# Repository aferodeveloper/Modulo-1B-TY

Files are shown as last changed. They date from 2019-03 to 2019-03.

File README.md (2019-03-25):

# INTRODUCTION
Modulo-1B-TY is a development board for the Afero ASR-1B Secure BLE radio architecture (based on the nRF52832 BLE chipset).  The Modulo-1B-TY uses the pre-certified Taiyo Yuden EYSHCNZWZ module + the Afero Hardware Security Module.

Additional Features:
 * Board supports power from USB as well as a Vin over a relatively wide voltage range
 * New and improved switch (first used on Modulo2a)
 * Use of the Taiyo Yuden EYSHCNZWZ module gives the board FCC/IC and Telec certification

For more information, please see the Afero developers site: https://developer.afero.io

# Design Information
The Modulo-1B-TY design was built using Altium.  The entire Altium project, including scripts that generate the output files, is included.

## Manifest (abridged)
 * **Modulo-1B-TY.PrjPcb** is the toplevel Altium project file.
 * **Modulo-1B-TY.SchDoc** is the Altium schematic file.
 * **Modulo-1B-TY.PcbDoc** is the Altium layout file.
 * **AssyDrawing.PCBDwf** and **FabDrawing.PCBDwf** are drawing templates for the Assembly and Fabrication drawings.
 * **outputs.OutJob** is the "script" for Altium that you can use to generate all of the needed output files (pdf files, gerbers, pick and place info, et cetera).
 * **Modulo-1B-TY.pdf** pdf of the schematics; autogenerated.
 * **Modulo-1B-TY-fabrication.pdf** pdf of the board fabrication drawing; autogenerated.
 * **Modulo-1B-TY-Assy.pdf** pdf of the assembly drawing; autogenerated.
 * **gerbers** is the directory where the Gerber output files and ODB++ files are located.  These are the files that one would use when you release the board to fab and assembly; autogenerated.
 * **gerbers/Modulo-1B-TY_BOM.xls** is the Bill of Materials for the board; autogenerated.
 * **LICENSE.txt** Apache 2.0 license governing the use of this design.
 * **NOTICE** Copyright information.
 * **README.md** This file.

Please note that the Afero Secure Radio stack firmware and hardware security modules included in the design are not publicly available.  Please contact Afero about licensing these items.

# CONTRIBUTORS
Original design by Afero, Inc.

Copyright 2018, 2019 Afero, Inc.

Licensed under the Apache 2.0 license; check LICENSE.txt for more information.  All text above must be included in any redistribution.

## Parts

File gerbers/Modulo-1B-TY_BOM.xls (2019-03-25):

item_number | Comment | Description | Quantity | Designator | Footprint | LibRef | Manufacturer | Manufacturer Part Number
E-CAP-00106-00 | 12pF | Capacitor, C0G | 3.0 | C1, C13, C14 | 0402C-GENERIC | 0402C-12p | Murata | GJM1555C1H120FB01D
E-CAP-00066-00 | 4.7uF | Capacitor | 4.0 | C2, C4, C8, C15 | 0603C-GENERIC | 0603C-4u7 | Murata | GRM188R61C475KAAJD
E-CAP-00004-00 | .1uF | Capacitor, MLCC | 4.0 | C3, C6, C9, C10 | 0402C-GENERIC | 0402C-100n | Murata | GRM155R61H104KE19D
E-CAP-00020-00 | 1uF | Capacitor, MLCC | 2.0 | C5, C7 | 0402C-GENERIC | 0402C-1u | Murata Electronics | GRM155R60J105ME19J
E-CAP-00019-00 | 47pF | Capacitor, C0G | 2.0 | C11, C12 | 0402C-GENERIC | 0402C-47p | Murata | GRM1555C1H470JZ01D
E-DIO-00010-00 | BAT54CL | Dual Common Cathode Schottky Diodes | 1.0 | D1 | SOT23 | BAT54CL | ON Semiconductor | BAT54CLT1G
E-LED-00009-00 | Orange | LED_0603 | 1.0 | D2 | 0603LED | LED_0603 | Vishay Lite-On | LTST-C190KAKT
E-DIO-00008-00 | TPD1E05U06 | TVS Diode | 5.0 | D3, D4, D5, D6, D7 | SON70P100X45-2N | TPD1E05U06 | Texas Instruments | TPD1E05U06DPYR
M-CON-00058-00 | HDR-1x18 |  | 2.0 | J1, J2 | HDR-1X18 | HDR-1x18
E-ICS-00091-00 | EYSHCNZWZ | Bluetooth 5.0 Low Energy Module | 1.0 | MOD1 | EYSHCNZWZ | EYSHCNZWZ | Taiyo Yuden | EYSHCNZWZ
 | 2N7002 | MOSFET N-CH 60V 115mA SOT23 | 1.0 | Q1 | SOT23 | Nch_MOSFET_2N7002 | On Semiconductor | 2N7002
E-RES-00039-00 | 4.7k | Resistor 4k7 | 2.0 | R1, R2 | 0402R-GENERIC | 0402R-4k7 | Panasonic | ERJ-2GEJ472X
E-RES-00008-00 | 100 | Resistor 100R | 2.0 | R3, R13 | 0402R-GENERIC | 0402R-100R | Vishay Dale | CRCW0402100RFKED
E-RES-00001-00 | 10k | Resistor 10k | 1.0 | R5 | 0402R-GENERIC | 0402R-10k | Vishay Dale | CRCW040210K0JNED
E-RES-00019-00 | 0 | Resistor 0R | 1.0 | R7 | 0603R-generic | 0603R-0R0 | Panasonic | ERJ-3GEY0R00V
E-RES-00012-00 | 100k | Resistor 100k | 1.0 | R8 | 0402R-GENERIC | 0402R-100k | Panasonic | ERJ-2GEJ104X
E-RES-00002-00 | 1k | Resistor 1k | 3.0 | R9, R10, R11 | 0402R-GENERIC | 0402R-1k | Yageo | RT0402-FRE071KL
E-RES-00007-00 | 27 | Resistor 27R | 2.0 | R12, R14 | 0402R-GENERIC | 0402R-27R | Vishay | CRCW040227R0FKED
item_name | 0 | Resistor 0R | 1.0 | R15 | 0402R-GENERIC | 0402R-0R0 | Yageo | RC0402FR-070RL
E-SWI-00020-00 | FSMSM | SMD Tact Switch | 1.0 | S1 | FSMSM | FSMSM | TE Connectivity Alcoswitch | FSMSM
E-ICS-00072-00 | ATECC508A | Afero Custom CryptoAuthentication Device | 1.0 | U1 | SON50P300X60-8N | ATECC508A | Microchip / Atmel | ATECC508A-MAHCZ-T
E-ICS-00092-00 | S-1313A33-M5T1U3 | Low Current Consumption LDO | 1.0 | U2 | SOT95P275X130-5N | S-1313A33-M5T1U3 | Seiko | S-1313A33-M5T1U3
E-ICS-00053-00 | FT230XQ | USB to UART Bridge | 1.0 | U3 | VQFN65P400X400X90-16N | FT230XQ | FTDI | FT230XQ-R
M-CON-00011-00 | 10103594-0001LF | MICRO USB B | 1.0 | USB1 | 10103594-0001LF | 10103594-0001LF | Amphenol FCI | 10103594-0001LF

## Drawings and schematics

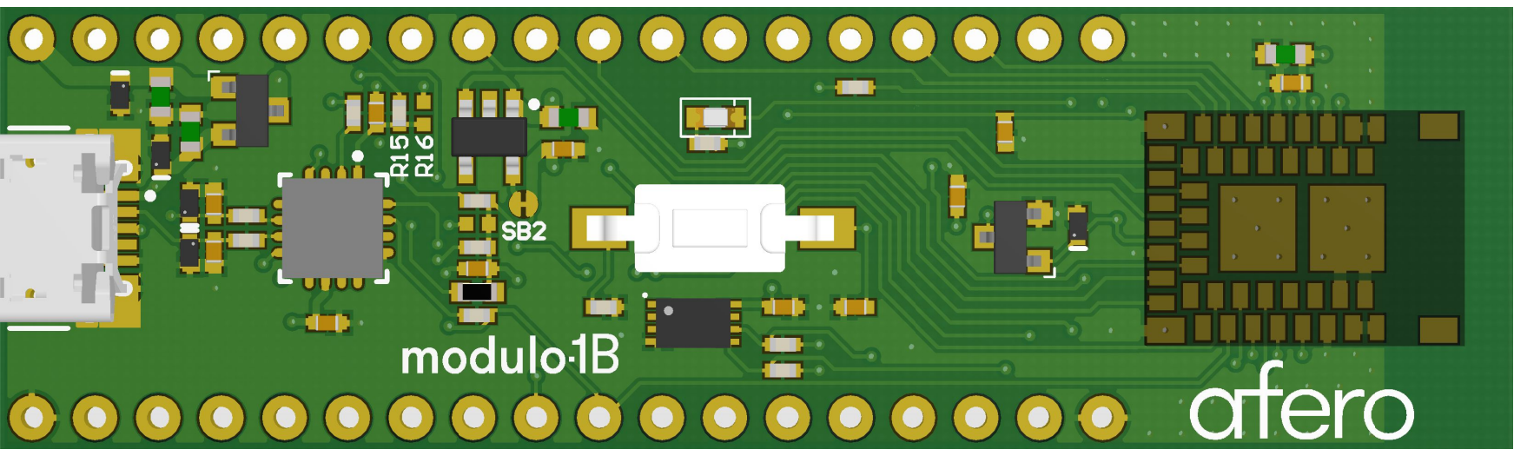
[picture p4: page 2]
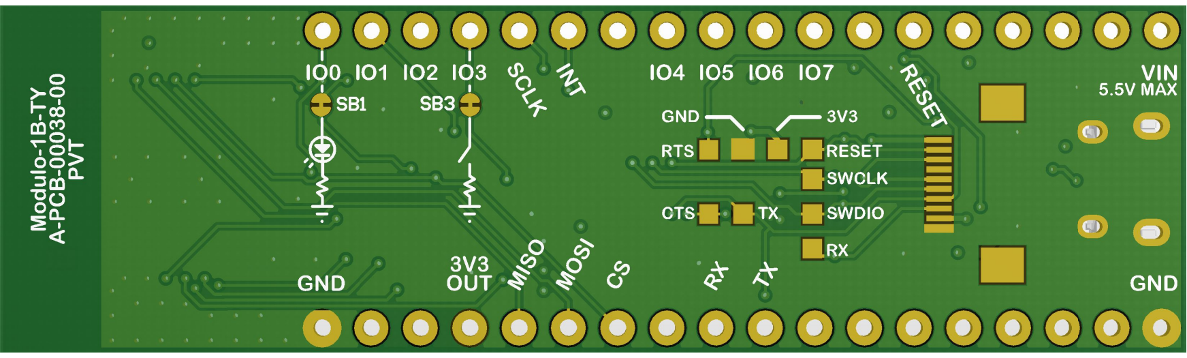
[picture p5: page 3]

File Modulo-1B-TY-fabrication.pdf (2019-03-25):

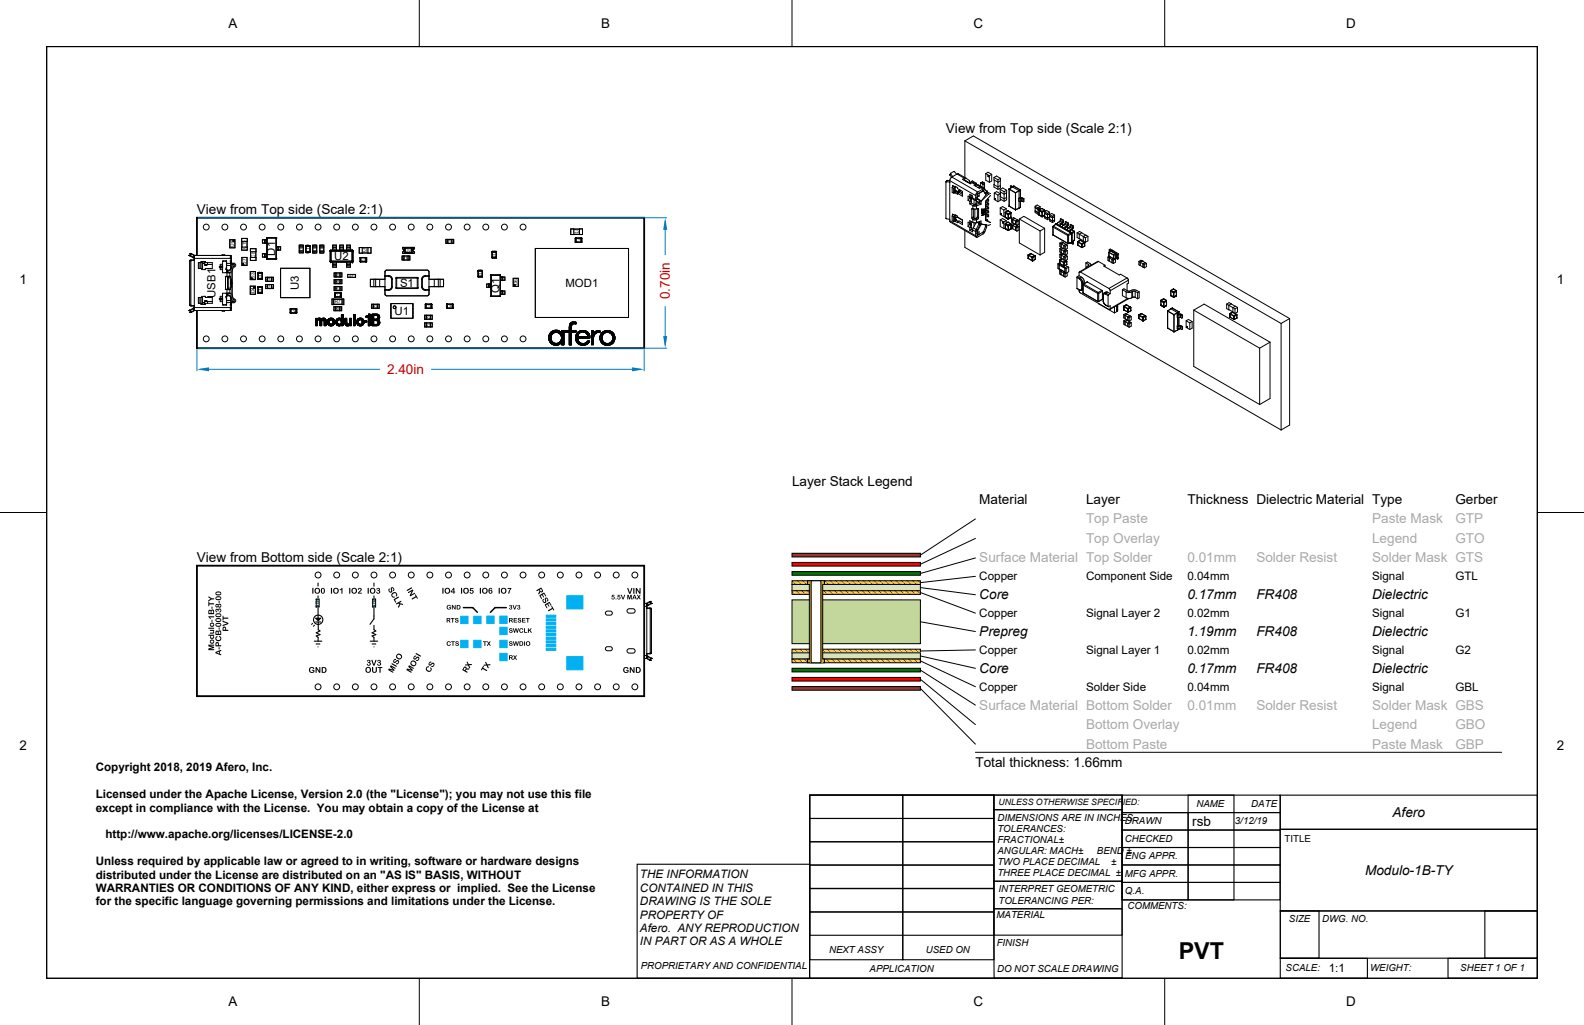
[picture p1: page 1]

View from Top side (Scale 2:1)

View from Bottom side (Scale 2:1)

Licensed under the Apache License, Version 2.0 (the "License"); you may not use this file
except in compliance with the License. You may obtain a copy of the License at

UNLESS OTHERWISE SPECIFIED:
DIMENSIONS ARE IN INCHES
TOLERANCES:
FRACTIONAL±
TWO PLACE DECIMAL ±
THREE PLACE DECIMAL ±
INTERPRET GEOMETRIC
TOLERANCING PER:
MATERIAL

http://www.apache.org/licenses/LICENSE-2.0

Unless required by applicable law or agreed to in writing, software or hardware designs
distributed under the License are distributed on an "AS IS" BASIS, WITHOUT
WARRANTIES OR CONDITIONS OF ANY KIND, either express or implied. See the License
for the specific language governing permissions and limitations under the License.

THE INFORMATION
CONTAINED IN THIS
DRAWING IS THE SOLE
PROPERTY OF
Afero. ANY REPRODUCTION
IN PART OR AS A WHOLE

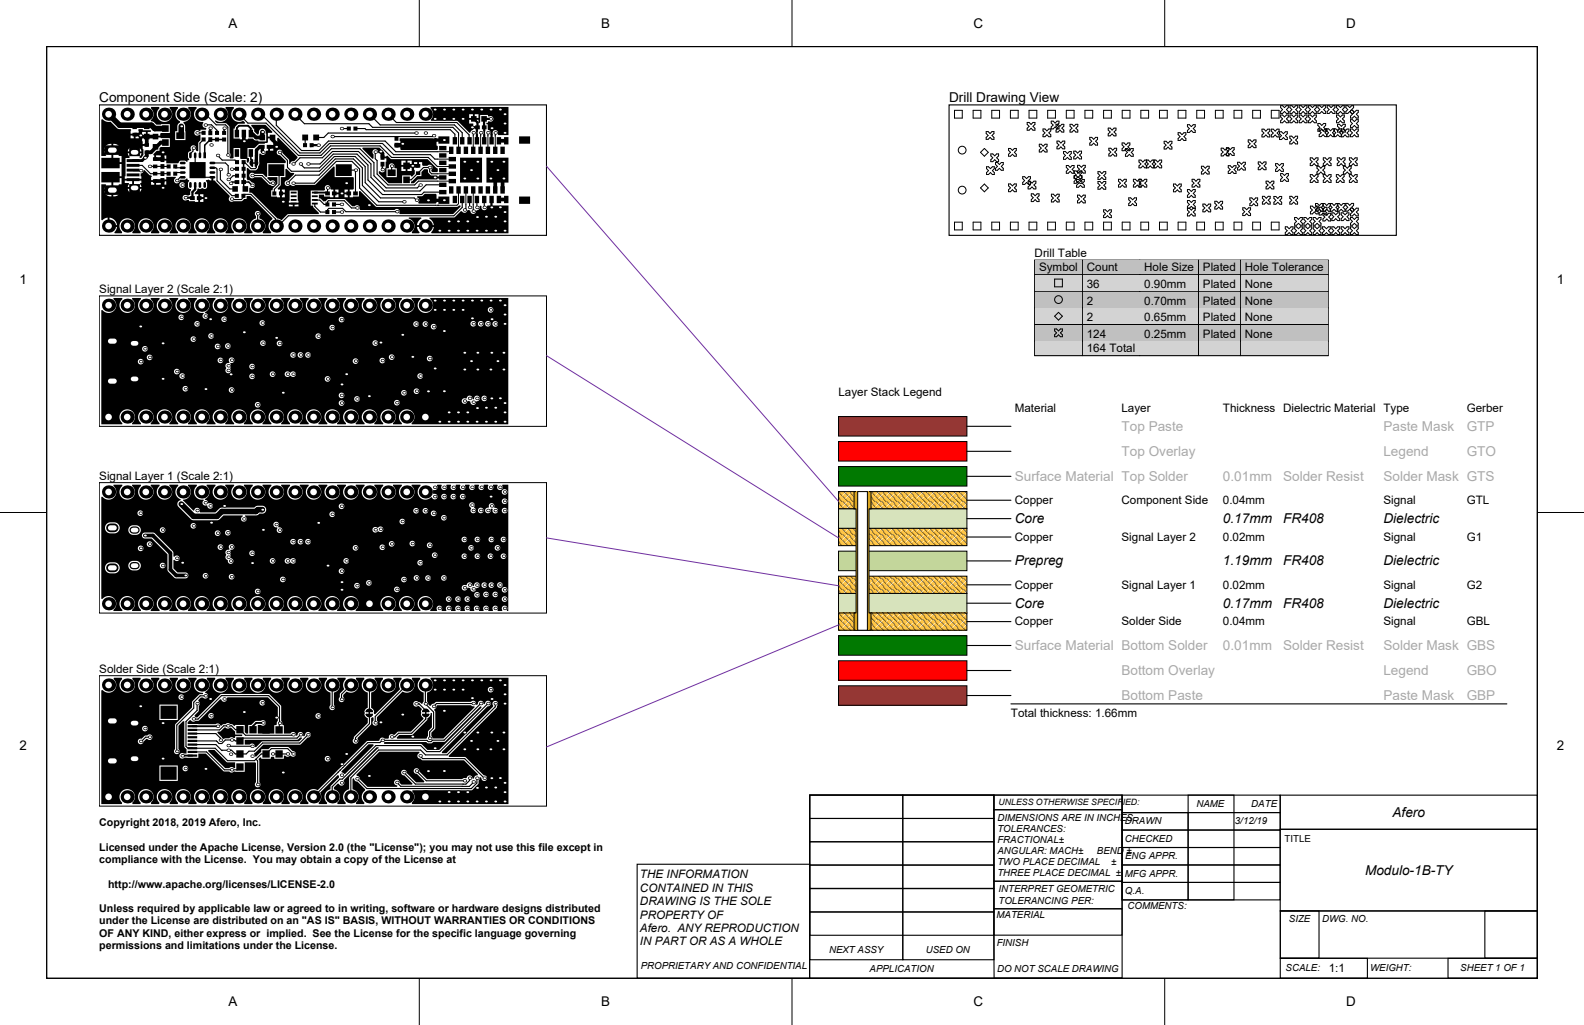
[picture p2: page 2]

Symbol | Count | Hole Size | Plated | Hole Tolerance

36 | 0.90mm | Plated | None
2 | 0.70mm | Plated | None
2 | 0.65mm | Plated | None
124 | 0.25mm | Plated | None
164 Total

UNLESS OTHERWISE SPECIFIED: | | NAME | DATE | Afero
DIMENSIONS ARE IN INCHES TOLERANCES: FRACTIONAL± ANGULAR: MACH± BEND ± TWO PLACE DECIMAL ± THREE PLACE DECIMAL ± | DRAWN | | 3/12/19

CHECKED | | | TITLE Modulo-1B-TY
ENG APPR.

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

THE INFORMATION CONTAINED IN THIS DRAWING IS THE SOLE PROPERTY OF Afero. ANY REPRODUCTION IN PART OR AS A WHOLE PROPRIETARY AND CONFIDENTIAL | | | MFG APPR.

http://www.apache.org/licenses/LICENSE-2.0

INTERPRET GEOMETRIC TOLERANCING PER: | Q.A.

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

MATERIAL | | SIZE | DWG. NO.

NEXT ASSY | USED ON | FINISH DO NOT SCALE DRAWING

APPLICATION | | | 1:1

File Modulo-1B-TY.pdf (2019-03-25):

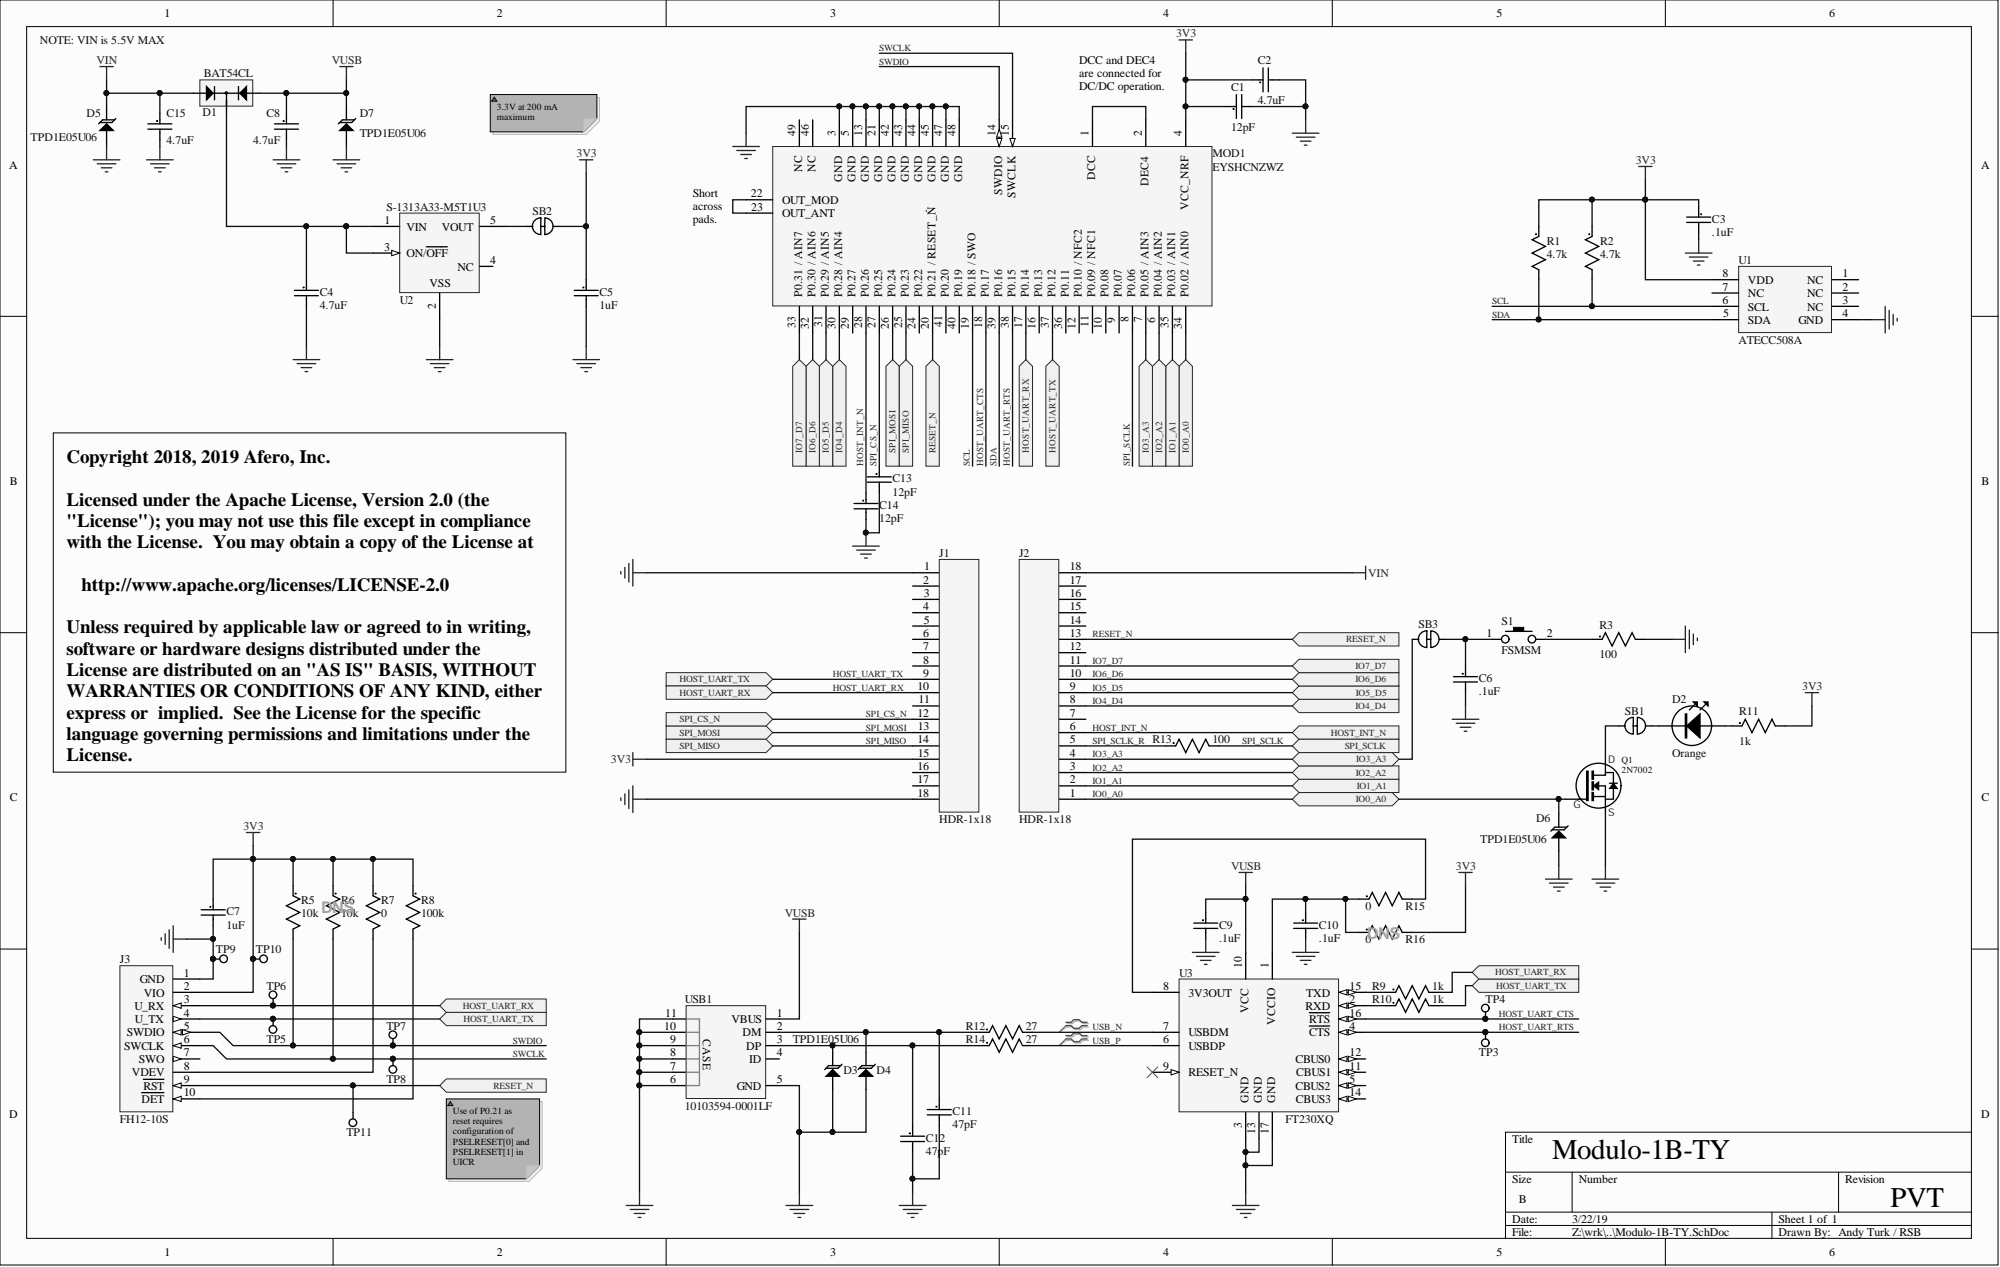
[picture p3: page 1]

NOTE: VIN is 5.5V MAX

Licensed under the Apache License, Version 2.0 (the
"License"); you may not use this file except in compliance
with the License. You may obtain a copy of the License at

http://www.apache.org/licenses/LICENSE-2.0

Unless required by applicable law or agreed to in writing,
software or hardware designs distributed under the
License are distributed on an "AS IS" BASIS, WITHOUT
WARRANTIES OR CONDITIONS OF ANY KIND, either
express or implied. See the License for the specific
language governing permissions and limitations under the
License.
